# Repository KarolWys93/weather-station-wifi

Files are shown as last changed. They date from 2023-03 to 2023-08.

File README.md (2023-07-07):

# weather-station-wifi
 **Useful links:**
 - [User Manual](Docs/user_manual.md)
 - [Electronics](Hardware/electronics/README.md)
 - [Device case](Hardware/case/README.md)
 - [Local development server](html/README.md)
 - [Web Server API](Docs/http_api_docs.md)
 - [Generation of display images](res/README.md)
 - [Preparation for first start](Docs/preparation.md)

## General description
This is a project of a weather station with WiFi module. The presented forecasts come from the [open-meteo](https://open-meteo.com/) service.

The device is based on the **STM32F103CBT6** microcontroller and the popular WiFi module: **ESP32-C3-WROOM-02**. The WiFi module uses AT command control mode. The project uses a 1.54" 3-color [e-Paper display](https://www.waveshare.com/1.54inch-e-paper-module-b.htm) with a resolution of 200x200 px.

Block diagram of the device:

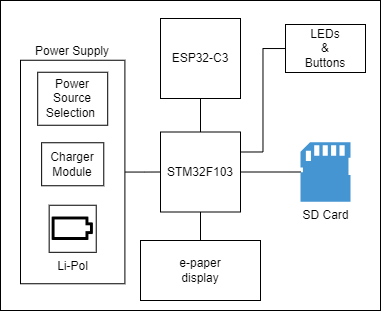
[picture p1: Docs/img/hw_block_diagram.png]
Block diagram of the device


There are two main parts of the firmware: **forecast client** and **http server**.

The task of the forecast client is to decode the postcode to the coordinates (if the coordinates are not provided directly), download the weather forecast for the given coordinates and display it on the e-paper display.

The HTTP server is used in configuration mode. In the configuration mode, the WiFi module starts its own AccessPoint, and the HTTP server provides the configuration website.

## Device visualization:
| Front of the device | 3D view of the device |
|--|--|
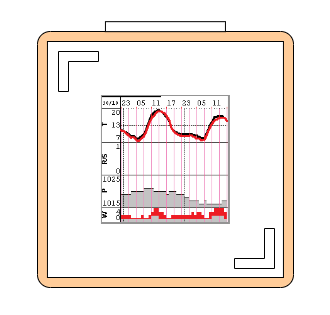
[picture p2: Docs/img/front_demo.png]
front of device
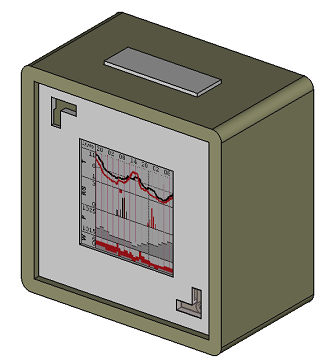
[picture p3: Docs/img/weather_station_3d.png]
3D device image
|  |  |
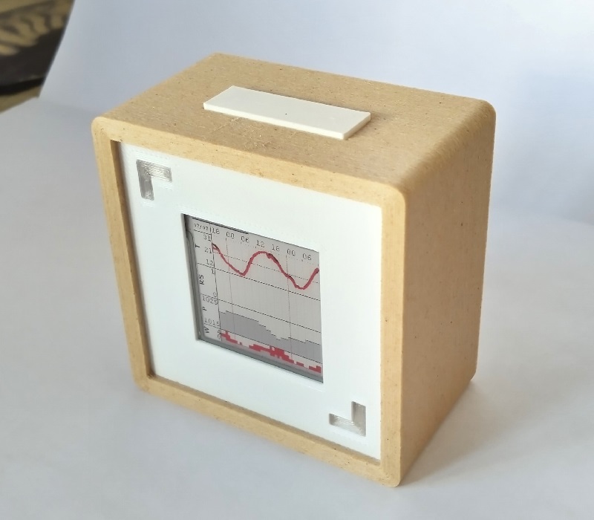
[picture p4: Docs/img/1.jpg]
photo of the device from the front
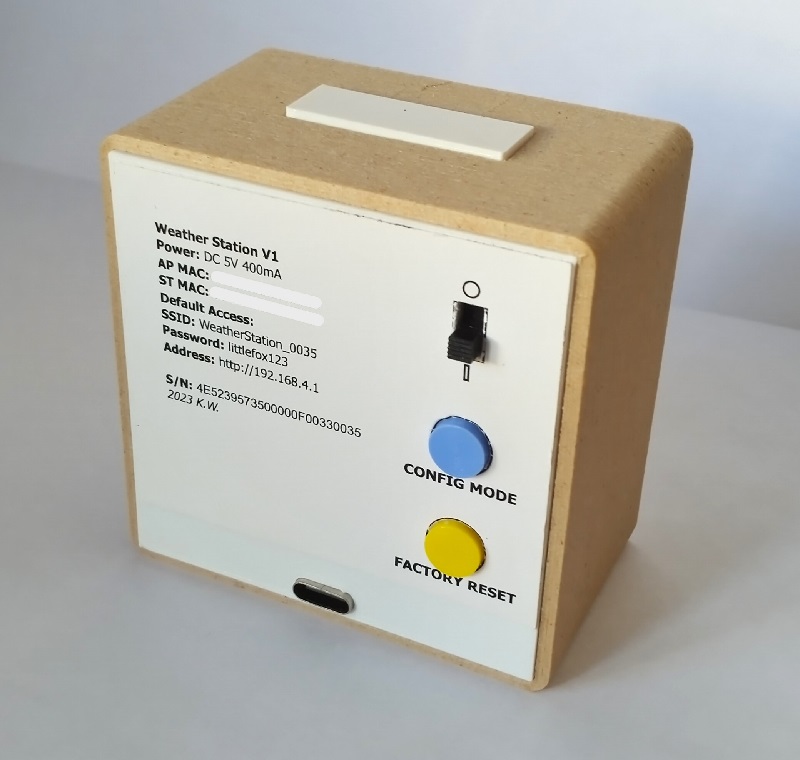
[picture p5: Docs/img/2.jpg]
photo of the device from the back
|  |  |

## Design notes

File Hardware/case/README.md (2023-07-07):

# Device case

The device case has been designed in FreeCad. The project file is stored in `Hardware/case/project` directory.
All case part models in .stl format can be found in `Hardware/case/models` directory.

## Device case scheme

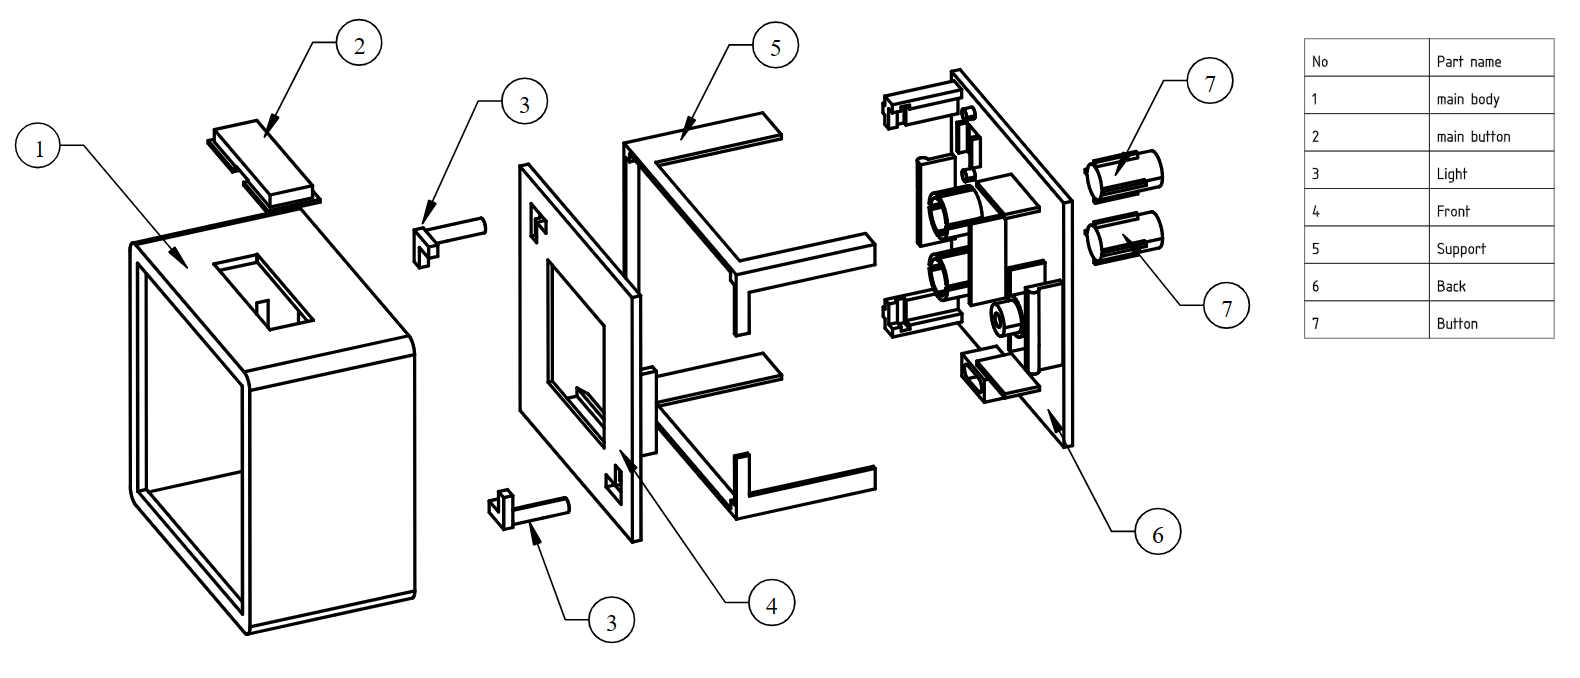
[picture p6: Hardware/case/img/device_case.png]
Device case schema


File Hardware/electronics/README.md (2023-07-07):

# Hardware

The scheme and PCB layout have been designed in KiCad. The project can be found in weather_station.zip archive.

## Jumpers and connectors
| J# | Description |
|--|--|
| J1 | MCU reset |
| J3 | MCU ISP: 1 - SWDIO, 2 - SWCLK, 3 - GND |
| J4 | MCU UART: 1 - RX, 2 - TX, 3 - GND |
| J5 | WiFi module boot mode: on - download mode. off - normal mode |
| J6 | E-Paper display |
| J7 | WiFi module UART: 1 - RXD, 2 - TXD, 3 - GND  |
| J8 | USB power line |
| J9 | Battery |
| J10 | Power switch |
| JP1 | WiFi module enable signal source: 1-2: MCU, 2-3: module always enabled |

## Electrical schematic

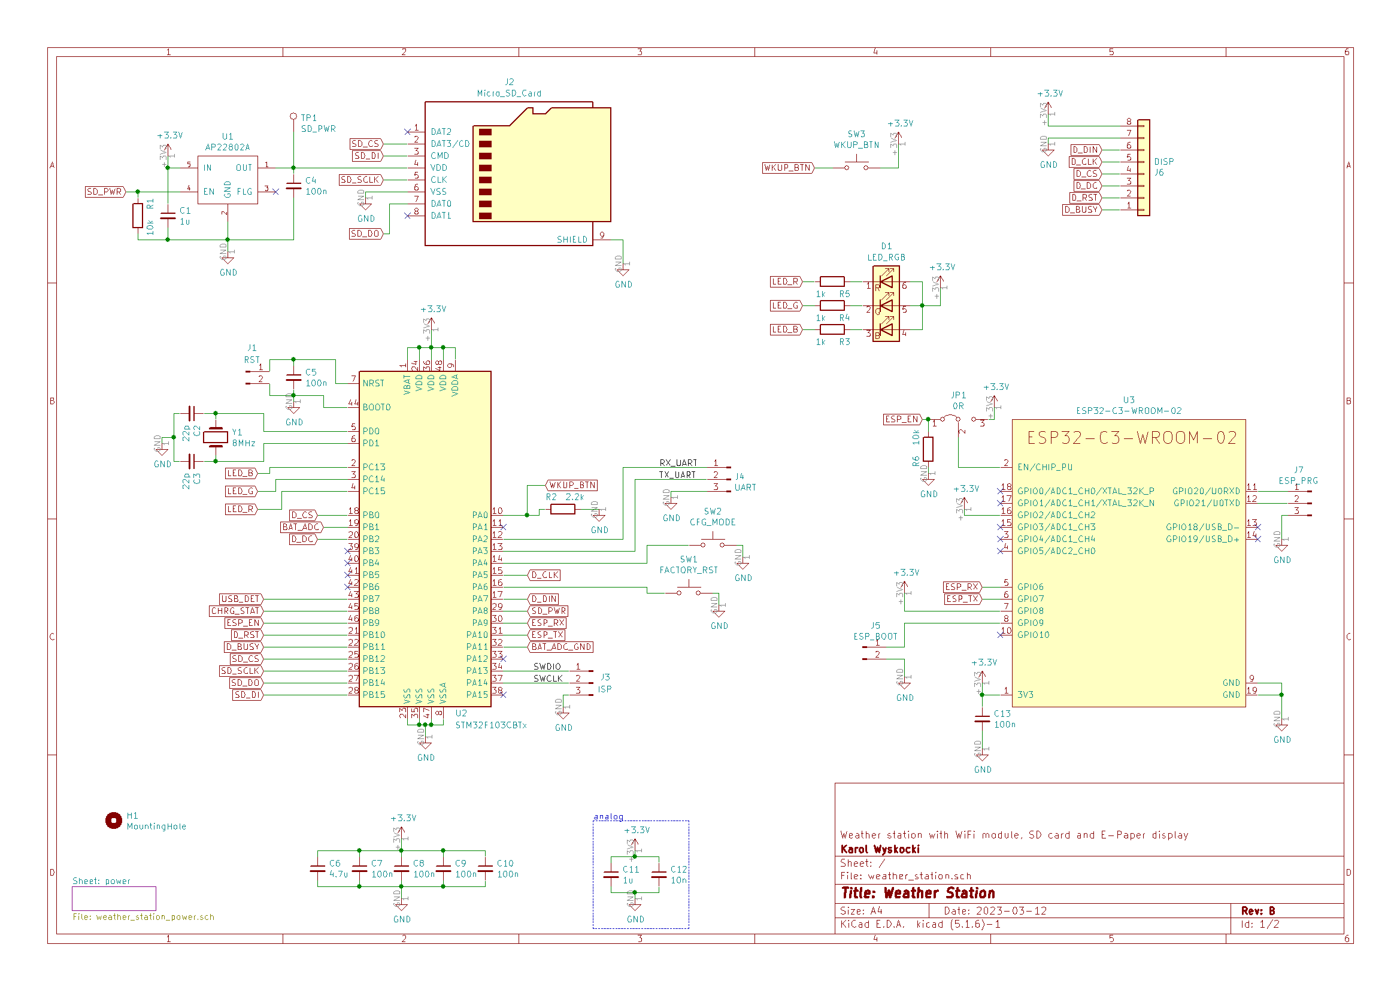
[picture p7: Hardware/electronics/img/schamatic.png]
Main schematic


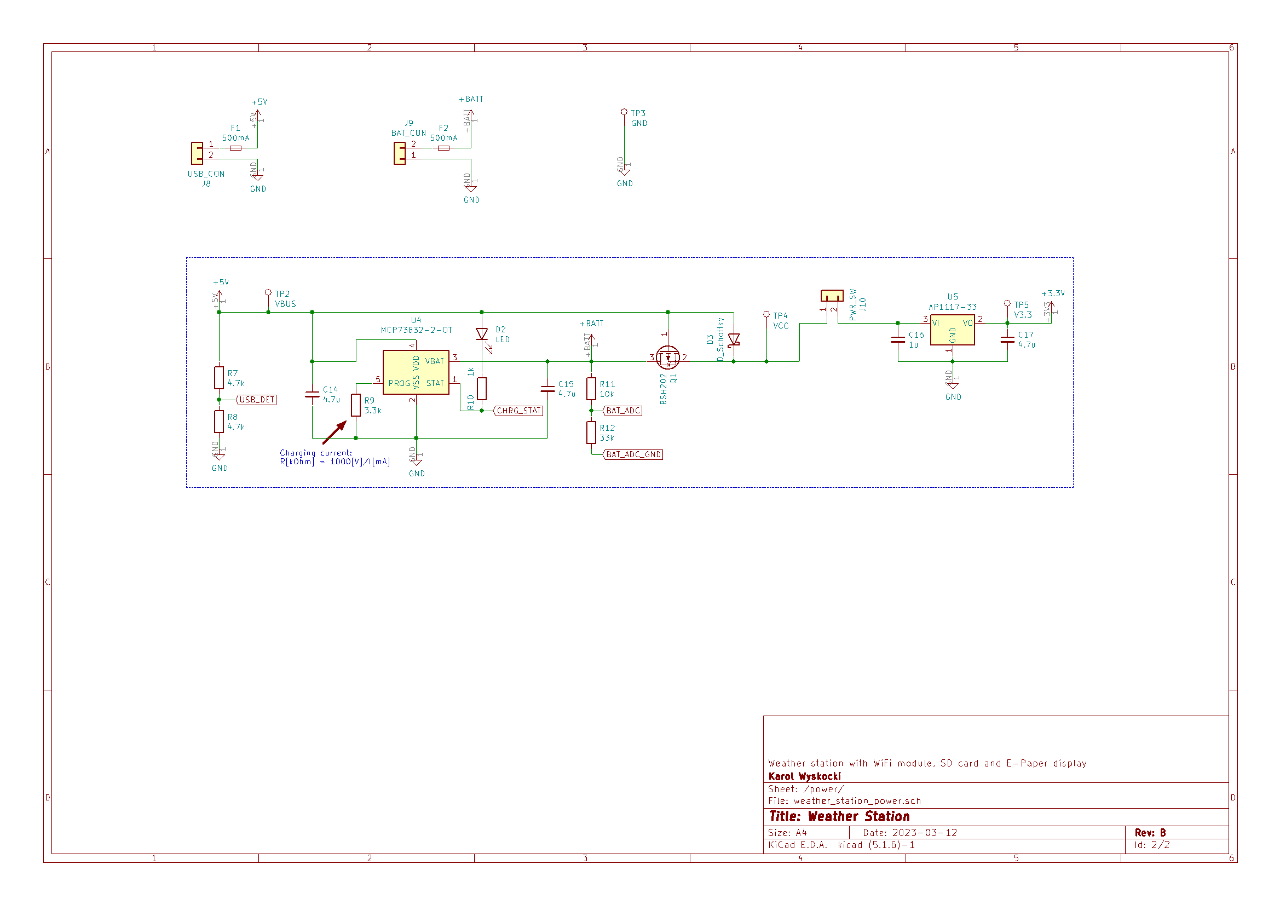
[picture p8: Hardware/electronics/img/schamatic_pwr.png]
Power source block


## PCB view:
| PCB top | PCB bottom |
|--|--|
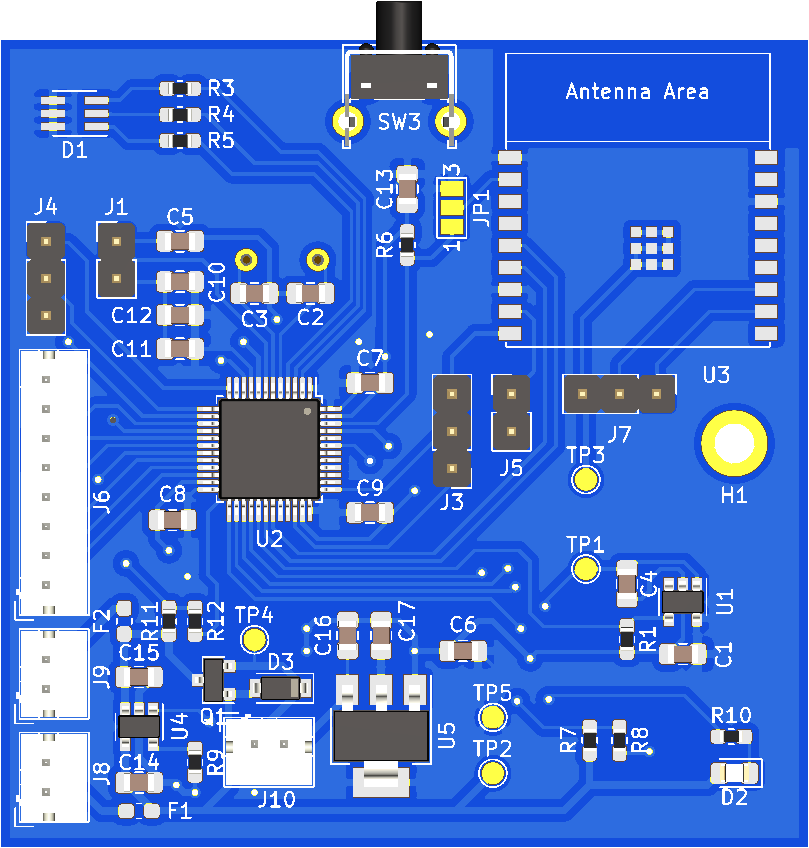
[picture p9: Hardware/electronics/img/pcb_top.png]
top
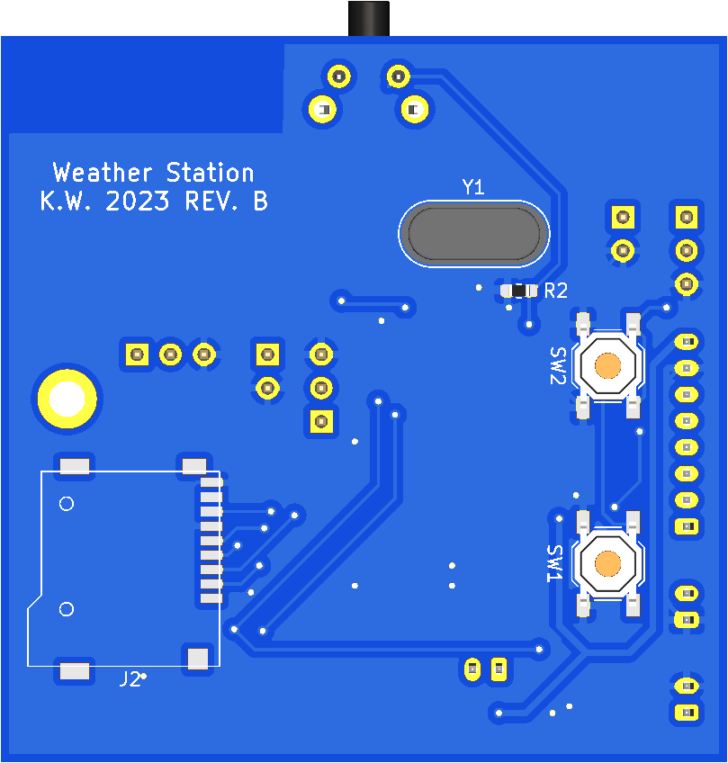
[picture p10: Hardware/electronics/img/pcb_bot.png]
bottom
|  |  |

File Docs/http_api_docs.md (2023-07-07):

# API Docs

## HTTP GET

### GET /api/status
Returns the current state of the device.

Response code: 200

Example of response:

    {
	  "wifi_ssid": "Testowa Sieć",
	  "wifi_stat": 1,
	  "bat": 43,
	  "ip_addr": "192.168.0.129",
	  "charging": 2,
	  "ver": "v1.3.1",
	  "sta_mac": "00:11:22:33:44:55",
	  "ap_mac": "AA:BB:CC:DD:EE:FF",
	  "ver_wifi": "2.1"
    }
Fields in response:

 - **wifi_ssid** - network name
 - **wifi_stat** - connection state: 1 - connected, 0 - disconnected
 - **bat** - battery level in %
 - **ip_addr** - device IP address
 - **charging** - charging status: 0 - no charging, 1 - charging, 2 - power supply on.
 - **ver** - software version
 - **sta_mac** - device MAC address (WiFi client)
 - **ap_mac** - MAC address of the access point (configuration mode)
 - **ver_wifi** - firmware version of the Wi-Fi module

### GET /api/ap_conf
Returns the current network settings of the access point (config mode).

Response code: 200

Example of response:

    {
	  "ap_ssid":"ConfigMode WiFi",
	  "ap_enc":"3",
	  "ap_chl":"8"
    }
Fields in response:
 - **ap_ssid** - network name
 - **ap_enc** - Access Point encryption: 0 - open, 2 - WPA PSK, 3 - WPA2 PSK, 4 - WPA WPA2 PSK
 - **ap_chl** - Wi-Fi channel (1-13)

### GET /api/ap_list
Returns Wi-Fi networks in range.

Response code: 200

Example of response:

    [
      {
        "ssid":"Example WiFi",
        "rssi":-40,
        "enc":4
      },
      {...},...
    ]
Fields in response:
 - **ssid** - network name
 - **enc** - encryption: 0 - open, 2 - WPA PSK, 3 - WPA2 PSK, 4 - WPA WPA2 PSK
 - **rssi** - Wi-Fi signal strength (dBm)

### GET /api/wifi_conf
Returns the current network settings.

Response code: 200

Example of response:

    {
	  "wifi_ssid": "Example WiFi",
	  "dhcp": 1,
	  "wifi_ip": "192.168.0.150",
	  "wifi_mask": "255.255.255.0",
	  "wifi_gw": "192.168.0.1"
    }
Fields in response:
 - **wifi_ssid** - network name
 - **dhcp** - dhcp status: 0 - disable, 1 - enable. Optional if DHCP is disabled.
 - **wifi_ip** - device IP address. Optional if DHCP is enabled.
 - **wifi_mask** - IP mask. Optional if DHCP is enabled.
 - **wifi_gw** - gateway IP address. Optional if DHCP is enabled.

### GET /api/fcast_conf
Returns the current forecast settings.

Response code: 200

Example of response where weather forecast location based on zip code:

    {
	  "api_key":"1234567890asdfghjklpqwertyuiop32",
	  "refresh":2,
	  "country":"PL",
	  "zip_code":"12-345"
    }
and for weather forecast location based on coordinates:

    {
	  "api_key":"1234567890asdfghjklpqwertyuiop32",
	  "refresh":2,
	  "lon": "89.9999999",
	  "lat": "89.9999999"
    }
Fields in responses:
 - **api_key** - geolocation service api key
 - **refresh** - how often the weather forecast is refreshed in hours
 - **country** - country code (ISO 3166-1 alpha-2 code)
 - **zip_code** - zip_code
 - **lon** - longitude
 - **lat** - latitude

### GET /api/system_conf
Returns the current system settings.

Response code: 200

Example of response:

    {
	  "device_name": "Potato1234",
	  "led_ind": 1
    }
Fields in response:
 - **device_name** - name of the device
 - **led_ind** - LED status indicator: 0 - off, 1 - on

### GET /api/restart
Restarts the device in forecast mode.

Response code: 204

### GET /api/restart_conf
Restarts the device in configuration mode.

Response code: 204

### GET /api/restore_config
Restores factory settings.

Response code: 204

## HTTP POST

### POST /api/ap_conf
Set access point configuration (for config mode).

Example request body:

    {
		"ap_ssid": "example_wifi",
		"ap_pass": "secret_password",
		"ap_enc": 4,
		"ap_chl": 8
	}

Request fields:
 - **ap_ssid** - Access Point WiFi name (max 31 chars)
 - **ap_enc** - Access Point encryption: 0 - open, 2 - WPA PSK, 3 - WPA2 PSK, 4 - WPA WPA2 PSK
 - **ap_pass** - Access Point password (min 8, max 62 chars). Not needed if ***ap_enc = 0***
 - **ap_chl** - channel of the access point (1-13)

Response code: 204

### POST /api/wifi_conf
Set WiFi configuration.

Example request body:

    {
		"ssid": "example_wifi",
		"pass": "secret_password",
		"dhcp": 0,
	    "ip": "192.168.0.150",
	    "mask": "255.255.255.0",
	    "gw": "192.168.0.1"
	}

Request fields:
 - **ssid** - WiFi name (max 31 chars)
 - **pass** - Access Point password. If there is no encryption, you can skip it.
 - **dhcp** - dhcp: 0 - disable, 1 - enable. If the field is omitted, DHCP is disabled.
 - **ip** - Device IP address. Required if DHCP is disabled.
 - **mask** - IP mask. Required if DHCP is disabled.
 - **gw** - Gateway IP address. Required if DHCP is disabled.

Response code: 200

Example of response:

    {
	  "code": 0
    }
    
Fields in response:
**code**: 
- 0: connected to the new WiFi station.
- 1: connection timeout.
- 2: wrong password.
- 3: cannot find the target AP.
- 4: connection failed.
- 5: Cannot disable DHCP or set IP addresses.

### POST /api/fcast_conf
Set forecast configuration. Forecast will use geolocation service if zip code and country code are present. Otherwise, the location is based on coordinates.

Example request body:

    {-
      "refresh": 2,
      "country": "PL",
      "zip_code": "12-345",
      "api_key": "1234567890asdfghjklpqwertyuiop32",
      "lon": 8.9999,
      "lat": 8.9999
    }
Request fields:
 - **refresh** - how often the weather forecast will be refreshed in hours. Must be greater than 0.
 - **country** (optional)- country code (ISO 3166-1 alpha-2 code)
 - **zip_code** (optional) - zip_code
 - **api_key** - geolocation service API key. Required if country or zip_code fields are present.
 - **lon** - longitude. Not nedded if country or zip_code fields are present.
 - **lat** - latitude. Not nedded if country or zip_code fields are present.

Response code: 204

### POST /api/device_name
Set device name.

Example request body:

    {
      "device_name": "example_device_name"
    }
Request fields:
 - **device_name** - Device name. The maximum length is 32 characters.

Response code: 204

### POST /api/led_ind
Set device name.

Example request body:

    {
      "led_ind": 1
    }
Request fields:
 - **led_ind** - 0: disable LED indicator, 1: enable LED indicator

Response code: 204

## Debug API

### GET /api/logs?size={size}
Returns device logs.

Call parameters:
 - **size** (optional) - Maximum log size in kB. The maximum value is 512, the default is 20.

Response code: 200

### GET /api/voltage
Returns power supply information.

Response code: 200

Example of response:

    {
      "voltage":"4021",
      "bat_lvl":99,
      "bat_chr":%u
    }

Fields in response:

 - **voltage** - battery voltage in mV
 - **bat_lvl** - battery level in %
 - **bat_chr** - charging status: 0 - no charging, 1 - charging, 2 - power supply on.

### GET /api/led_test
Checks the LED indicator. The LED indicator flashes through all combinations of 8 colors.

Response code: 204

### GET /api/img_test?img={int}&text={text}&sub_text={text}

To check the display, it shows the selected image with text on the device.
Returns device logs.
Call parameters:
 - **text** (optional) - primary text, no longer than 40 bytes. Default empty.
 - **sub_text** (optional) - secondary text, no longer than 50 bytes. Default empty.
 - **img** (optional) - Image number. Default value is 2.

Images:

 0. memory card error image
 1. blank forecast background (text and subtext are not used)
 2. config mode image (text and subtext are not used)
 3. low battery image (text and subtext are not used)
 4. WiFi error image
 5. General error image

Response code: 204 on success or 400 on invalid img number

### GET /api/fcast_tmp
Returns the last forecast file

Response code: 200 on success or 404 if the file does not exist.

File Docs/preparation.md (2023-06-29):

# Preparation for first start

## WiFi module

The device's WiFi module should be programed with AT command firmware. The firmware and all needed tools can be found in links below.

ESP32 AT module firmware:
https://docs.espressif.com/projects/esp-at/en/latest/esp32c3/AT_Binary_Lists/ESP32-C3_AT_binaries.html

ESP32 tools and downloading guide:
https://docs.espressif.com/projects/esp-at/en/latest/esp32c3/Get_Started/Downloading_guide.html

### Jumpers and connectors:
- JP1 - select ESP_Enable signal source: 1-2: MCU, 2-3: module always enabled
- J5 - Jumper on: download mode. Jumper off: normal mode
- J7 - ESP32 uart connector: 1 - RXD, 2 - TXD, 3 - GND 

Before flashing, the JP1 solder bridge should connect pins 2 and 3 to make sure the module is powered on when firmware downloading.
Jumper J5 must be connected before powering on to enter download mode.

## MCU

- J1 - Connect to reset STM32F1 MCU.
- J3 - MCU programming connector: 1 - SWDIO, 2 - SWCLK, 3 - GND

## SD Card preparation
The device uses an SD memory card to store static HTML files, graphics, configurations and logs. The first partition on the memory card should be formatted as FAT32 with a block size of 512B. Partition size can be up to 2GB.

Fresh formated memory card should contains directories:
- `img` - contains images (see [Generation of display images](../res/README.md))
- `html` - contains static html files (see [Local development server](../html/README.md))

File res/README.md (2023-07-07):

# Images

The E-Paper display used in the device has a resolution of 200x200 pixels and supports up to 5 colors: black, white, red, gray and pink. The display driver uses 3 "images" for black, gray and pink. A red color pixel is obtained when the same pixel is set for a black and pink "image".

## Image list

Here is the list of images used in system. Every image has its own index:

- 0 - memory error image *
- 1 - forecast background image *
- 2 - configuration mode image
- 3 - Low battery image
- 4 - wifi error image
- 5 - general error image

Memory error and forecast background images are loaded from the FLASH memory. The rest of the images are stored on the SD memory card. Images on the SD card are stored in **/img/** directory as epd files. The file name format is:
***/img/x_y.epd***
Where *x* is index and *y* is color. Example:
*/img/2_b.epd  
/img/2_g.epd  
/img/2_r.epd*

The example shows configuration mode images for black, grey and red display colors. It isn't mandatory to provide epd file if it is blank.

## Creating and converting images

Images should have a resolution of 200x200 pixels and use only the colors listed:
0x000000 : black  
0xED1C24 : red  
0xC3C3C3 : grey  
0xEF88BE : pink  
0xFFFFFF : white

Prepared image have to be split into monochrome bitmaps using script ***color_split.py***. Example:

`python res/scripts/color_split.py res/low_bat.bmp`

The result is 3 monochrome bitmaps:
*low_bat_b.bmp  
low_bat_g.bmp  
low_bat_r.bmp*

### Converting to file
Now these bitmaps should be converted to edp files. edp file is a raw image buffer for displaying e-paper.
The conversion can be done using the script ***epd_conv.py***. Example:

`python res/scripts/epd_conv.py res/low_bat_b.bmp`

The result is *low_bat_b.epd* file.
Now the file can be moved to the SD card (and renamed respectively).

### Converting to code
If image should be stored in FLASH memory, then image file can be converted to code (text). Example:

`python res/scripts/epd_conv.py -t res/low_bat_b.bmp`

The output is a text file. The content of the file should be copy to source code as array.

## "Screenshots" and back conversion

For debugging purposes, display buffers can be dumped to files. The dumps are saved as epd files in ***/img/scr*** directory.
The epd files can be converted to image using script ***scr2img.py***. Example:

`python res/scripts/scr2img.py b.epd g.epd r.epd output_img.bmp`

## Dependences

All the mentioned python scripts require the numpy and PIL libraries.

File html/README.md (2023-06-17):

# HTML static files

The html directory contains all the necessary static files for the device's web server. The api_mock directory contains mock APIs for testing the server on a local machine. These mocks are examples of server responses to various requests.
The device stores all website static files in the *'html"* directory on the SD card.

## Static files compression 
The http server always returns static files compressed with gzip (Content-Encoding set as gzip). The web server does not have a compression function implemented, so static files must be compressed beforehand.
To prepare the files for the server, run the ***compress.sh*** script.
The script creates a new directory *"compressed"*, copies the *"html"* directory there and compresses all files to the desired format. The *"html"* directory from the *"compressed"* directory can be copied to the root directory of the SD card.

## Test server
The test server can be used to test a website locally without the weather station device.
To enable test server, run the ***server_test.bat*** script. The script copies the static and mock files to the "test_server" directory and then starts a simple Python HTTP server. The server is listening for a connection on port **8000**.
The server works on a copy of the files, so any changes will be visible after restarting the server.

## Server web API
The web server API documentation can be found [here](../Docs/http_api_docs.md).

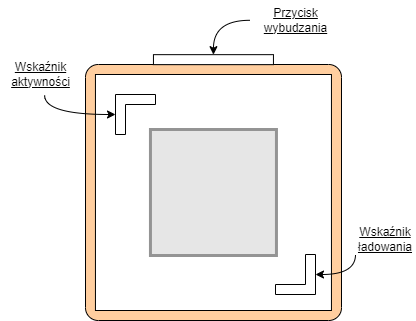
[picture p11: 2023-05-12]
html/html/pl/img/front.png

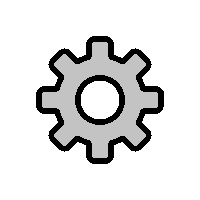
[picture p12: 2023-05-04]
res/settings.bmp

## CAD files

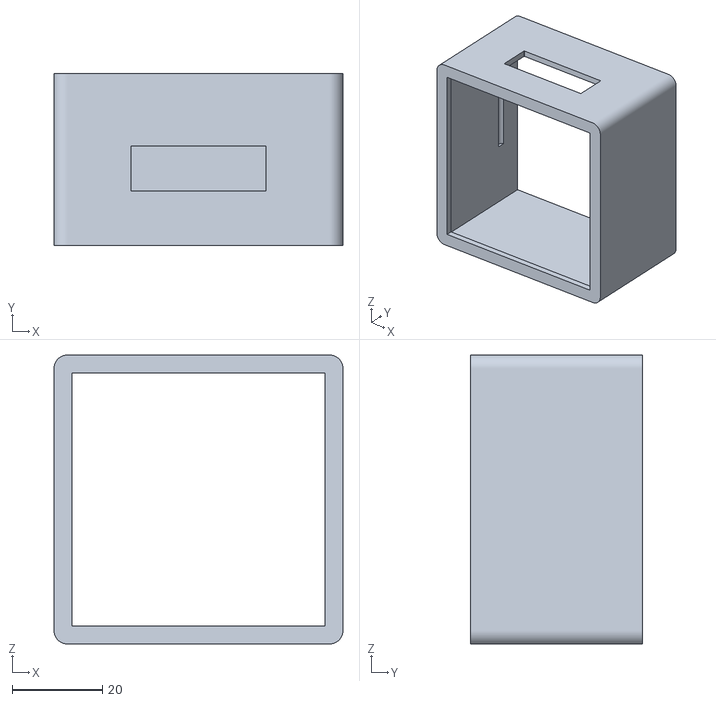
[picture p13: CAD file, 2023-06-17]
Hardware/case/models/main_body.stl
64.0 x 38.0 x 64.0

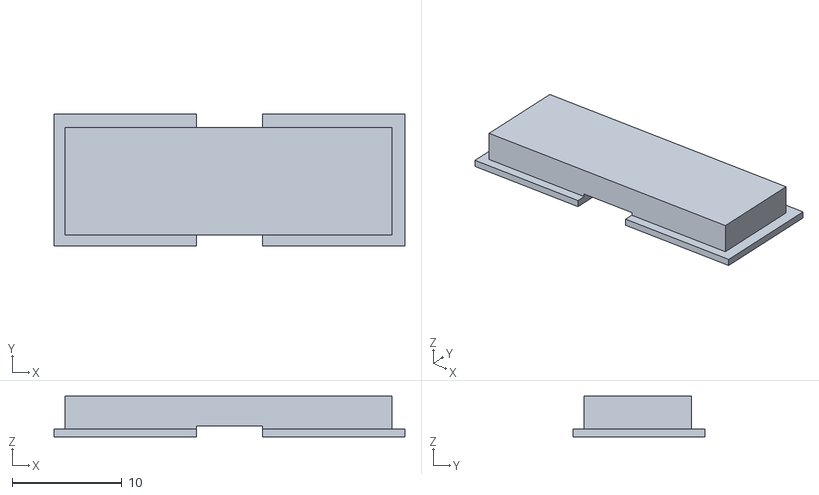
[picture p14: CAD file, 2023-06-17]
Hardware/case/models/button_main.stl
32.0 x 12.0 x 3.70

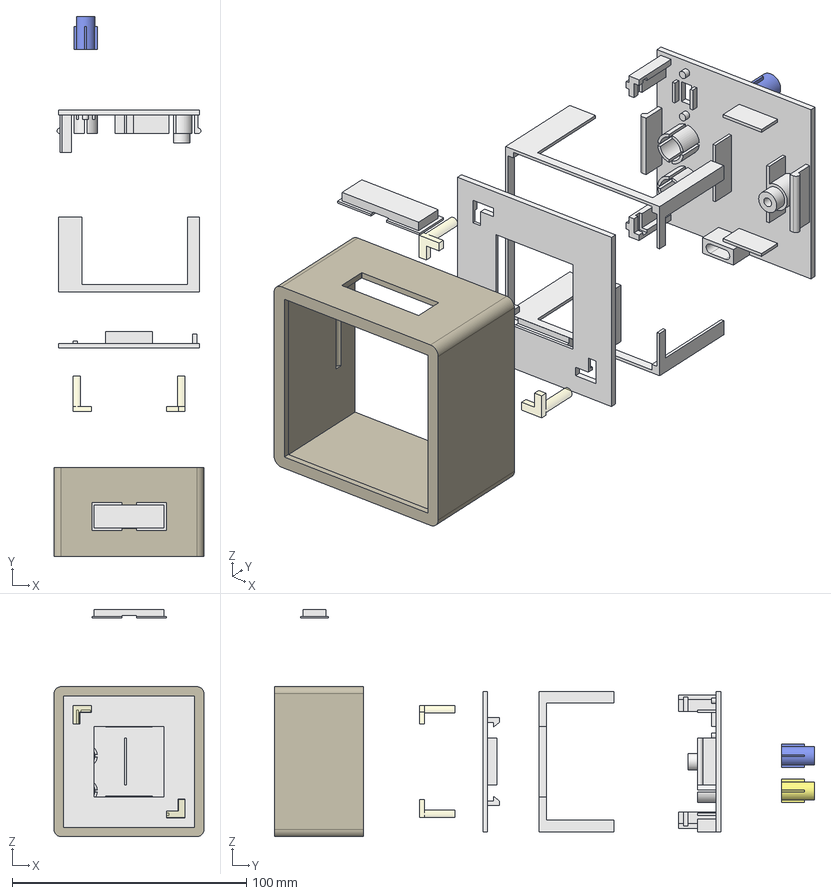
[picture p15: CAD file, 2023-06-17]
Hardware/case/project/weather_station.FCStd
64.0 x 230.5 x 97.0 mm
front
main_body
light
light_clone
back
button
button_main
button_clone
support

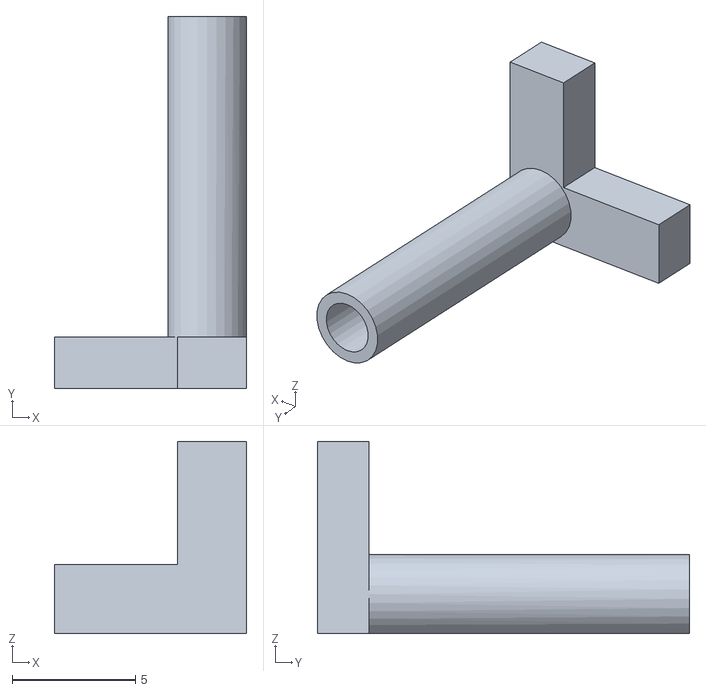
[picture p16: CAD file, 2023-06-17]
Hardware/case/models/light.stl
7.80 x 15.1 x 7.80

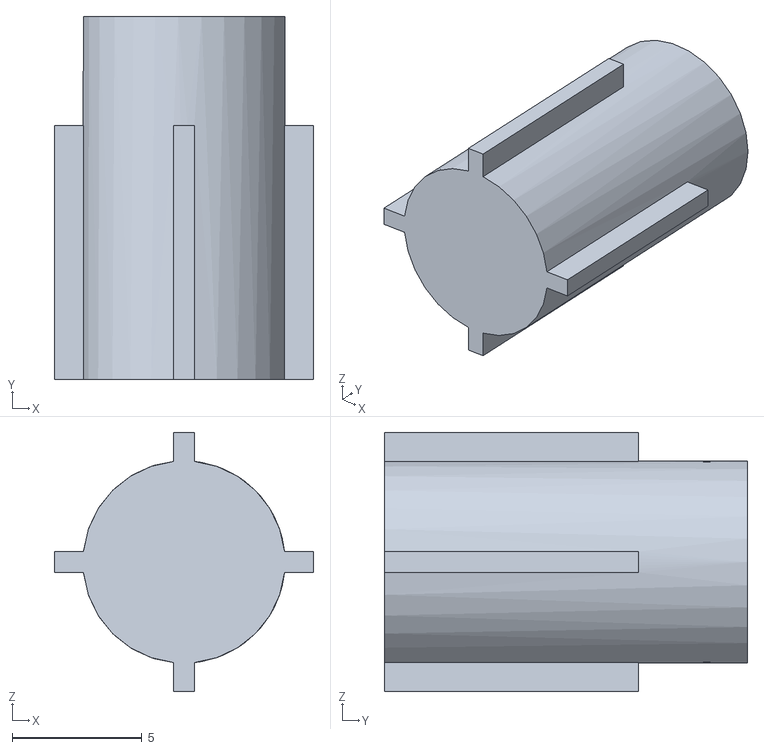
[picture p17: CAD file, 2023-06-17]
Hardware/case/models/button.stl
10.0 x 14.0 x 10.0

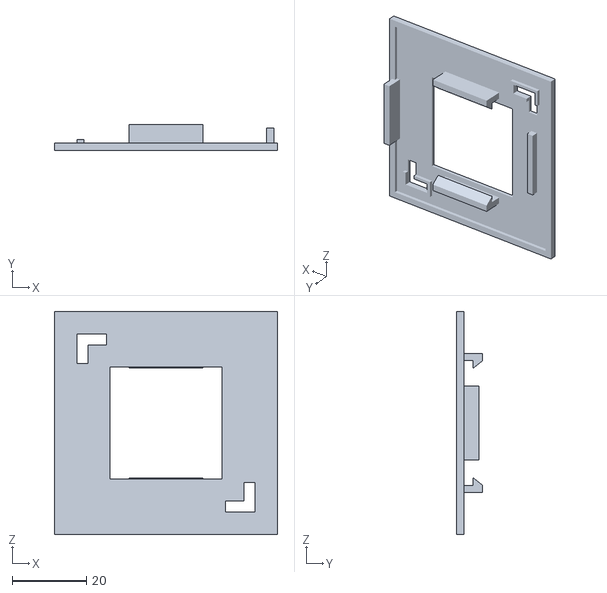
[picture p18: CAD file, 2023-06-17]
Hardware/case/models/front.stl
60.0 x 7.00 x 60.0

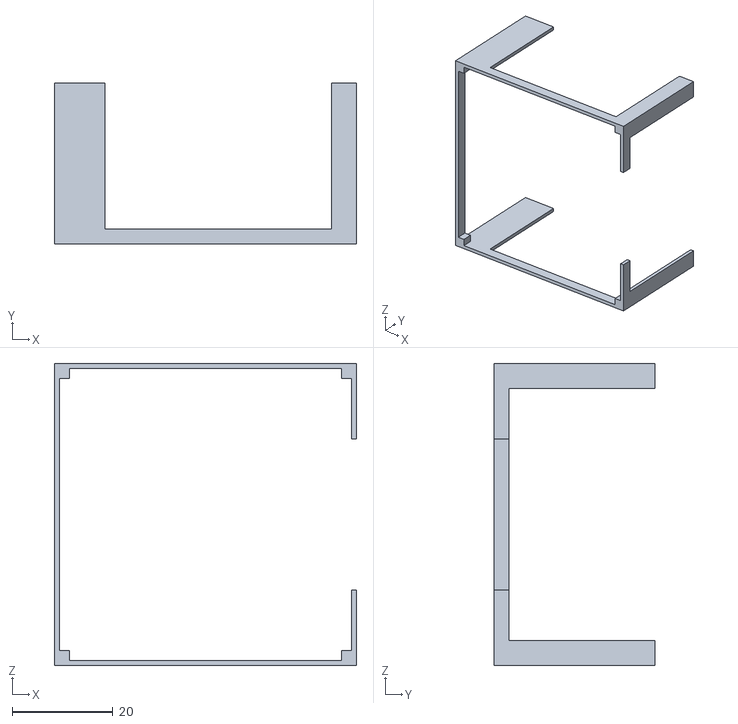
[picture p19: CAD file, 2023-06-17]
Hardware/case/models/support.stl
60.0 x 32.0 x 60.0

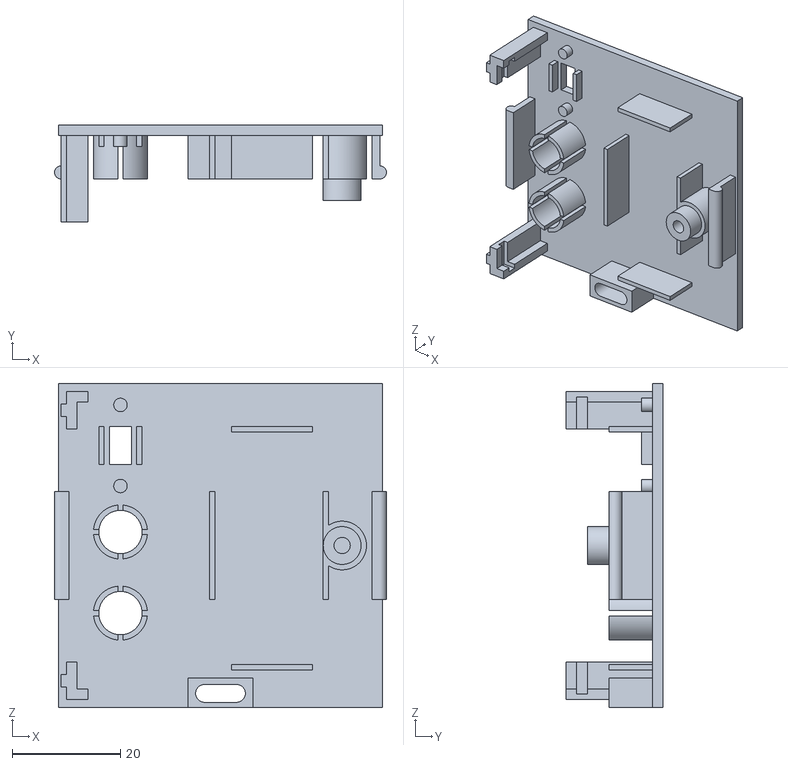
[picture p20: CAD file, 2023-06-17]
Hardware/case/models/back.stl
61.4 x 18.0 x 60.0

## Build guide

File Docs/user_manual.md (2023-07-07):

# User manual

## Front of the device

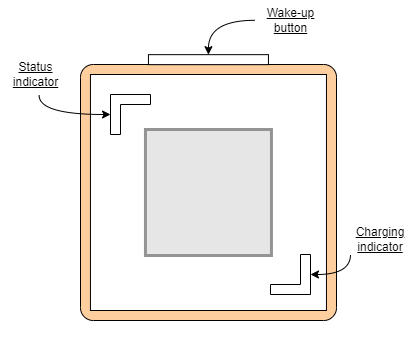
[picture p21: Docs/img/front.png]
front view of device


*   **Charging indicator:** Lights up when charging is in progress.
*   **Status indicator:**
    *   green - device is active
    *   blue - device in config mode
    *   red - error occurred
    *   yellow - indicates restart after hang-up condition
    *   cyan - factory reset
    *   white - critical error occurred. Manual restart needed
    *   **Wake-up button:** Wakes the device from sleep mode.

## Forecast display

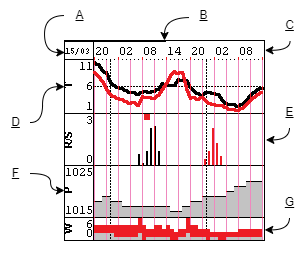
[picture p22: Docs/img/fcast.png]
example forecast display


Legend:

*   **A -** Forecast date.
*   **B -** Battery level.
*   **C -** Time line. The pink vertical line separates the 3 hour segments. The dashed line separates the days.
*   **D -** Temperature in °C. The black line is the real temperature, the red line is the apparent temperature.
*   **E -** Rain (black) in mm and snowfall (red) in cm. The red square means a storm.
*   **F -** Atmospheric pressure in hPa.
*   **G -** Wind speed (grey) and gusts (red) in Beaufort scale.

| Beaufort number | Description | Wind speed |
|--|--|--|
| 0 | Calm | < 2 km/h, < 0.5 m/s |
| 1 | Light air | 2-5 km/h, 0.5-1.5 m/s |
| 2 | Light breeze | 6-11 km/h, 1.6-3.3 m/s |
| 3 | Gentle breeze | 12-19 km/h, 3.4-5.5 m/s |
| 4 | Moderate breeze | 20-28 km/h, 5.6-7.9 m/s |
| 5 | Fresh breeze | 29-38 km/h, 8.0-10.7 m/s |
| 6 | Strong breeze | 39-49 km/h, 10.8-13.8 m/s  |
| 7 | High wind | 50-61 km/h, 13.9-17.1 m/s |
| 8 | Gale | 62-74 km/h, 17.2-20.7 m/s |
| 9 | Strong gale | 75-88 km/h, 20.8-24.4 m/s |
| 10 | Storm | 89-102 km/h, 24.5-28.4 m/s |
| 11  | Violent storm | 103-117 km/h, 28.5-32.6 m/s |
| 12 | Hurricane-force | ≥ 118 km/h, ≥ 32.7 m/s |

## Config mode

To enter the configuration mode, hold the blue button on the back of the device and at the same time wake up the device by pressing the wake-up button (on the top of the case) or turning on the power (power switch).

In config mode, the device enables its own WiFi Access Point. The default WiFi name is **WeatherStation\_xxxx** (where xxxx is the end of the serial number) and the password is **littlefox123**. The default WiFi name and password can be changed in the Access Point tab.

The configuration website is available at http://192.168.4.1. To exit the configuration mode, hold down the wake button or select the appropriate option in the System tab.

## Factory reset

The device can be restored to the default settings in System tab. A factory reset can also be performed by holding down the yellow button on the back of the device while switching power on. After the factory reset, the device will reboot into configuration mode.

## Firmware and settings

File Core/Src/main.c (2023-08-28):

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
/* Includes ------------------------------------------------------------------*/
#include "main.h"
#include "adc.h"
#include "dma.h"
#include "fatfs.h"
#include "rtc.h"
#include "spi.h"
#include "tim.h"
#include "usart.h"
#include "gpio.h"

/* USER CODE BEGIN Includes */
#include <stdlib.h>
#include <stdio.h>
#include <string.h>
#include "wifi/wifi_esp.h"
#include "system.h"
#include "jsmn.h"
#include "app/server/httpServerApp.h"
#include "app/client/forecast_client.h"
#include "logger.h"
#include "utils.h"

#include "led.h"
#include "images.h"
#include "sw_watchdog.h"
#include "GUI/GUI_Paint.h"
#include "e-Paper/EPD_1in54b.h"
/* USER CODE END Includes */


/* USER CODE BEGIN PV */
char deviceName[32] = "";
/* USER CODE END PV */

void SystemClock_Config(void);
/* USER CODE BEGIN 0 */

Wifi_RespStatus loadWiFiAPConfig(void)
{
	SWiFi_AP_Config ap_config;
	FIL configFile;

	char apConfigStr[256];
	uint16_t apConfigSize = 0;

	jsmn_parser jsonParser;
	jsmntok_t jsonTokens[10];
	int16_t numOfTokens;

	uint16_t tokenSize;
	char* tokenPtr;

	DMA_memset(&ap_config, 0, sizeof(SWiFi_AP_Config));

	jsmn_init(&jsonParser);

	if(FR_OK == f_open(&configFile, FILE_PATH_AP_CONFIG, FA_READ))
	{
		if(FR_OK != f_read(&configFile, apConfigStr, sizeof(apConfigStr), (UINT*)&apConfigSize))
		{
			f_close(&configFile);
			Logger(LOG_ERR, "Cannot read AP config");
			return WIFI_RESP_ERROR;
		}
		f_close(&configFile);
	}
	else
	{
		Logger(LOG_ERR, "Cannot open AP config");
		return WIFI_RESP_ERROR;
	}

	numOfTokens = jsmn_parse(&jsonParser, apConfigStr, apConfigSize, jsonTokens, sizeof(jsonTokens) / sizeof(jsonTokens[0]));
	if(0 > numOfTokens || jsonTokens[0].type != JSMN_OBJECT)	//if no tokens or first token isn't object
	{
		Logger(LOG_ERR, "AP config corrupted");
		return WIFI_RESP_ERROR;
	}

	for(uint16_t i = 1; i < numOfTokens; i++)
	{
		if(0 == jsmn_eq(apConfigStr, &jsonTokens[i], "ssid"))
		{
			tokenSize = jsonTokens[i + 1].end - jsonTokens[i + 1].start;
			tokenPtr = apConfigStr + jsonTokens[i + 1].start;
			DMA_memcpy(ap_config.ssid, tokenPtr, tokenSize);
			i++;
		}
		else if(0 == jsmn_eq(apConfigStr, &jsonTokens[i], "pass"))
		{
			tokenSize = jsonTokens[i + 1].end - jsonTokens[i + 1].start;
			tokenPtr = apConfigStr + jsonTokens[i + 1].start;
			DMA_memcpy(ap_config.pass, tokenPtr, tokenSize);
			i++;
		}
		else if(0 == jsmn_eq(apConfigStr, &jsonTokens[i], "enc"))
		{
			WiFi_Encryption encVal = (WiFi_Encryption)atoi(apConfigStr + jsonTokens[i + 1].start);
			ap_config.enc = encVal;
			i++;
		}
		else if(0 == jsmn_eq(apConfigStr, &jsonTokens[i], "channel"))
		{
			uint8_t channelVal = atoi(apConfigStr + jsonTokens[i + 1].start);
			ap_config.channel = channelVal;
			i++;
		}
		else
		{
			i++;
		}
	}

	ap_config.maxConnection = 1;

	return WiFi_AP_mode(&ap_config);
}

/* USER CODE END 0 */

/**
  * @brief  The application entry point.
  * @retval int
  */
int main(void)
{
  /* MCU Configuration--------------------------------------------------------*/

  /* Reset of all peripherals, Initializes the Flash interface and the Systick. */
  HAL_Init();

  /* Configure the system clock */
  SystemClock_Config();

  /* Initialize all configured peripherals */
  MX_GPIO_Init();
  MX_DMA_Init();
  MX_ADC1_Init();
  MX_RTC_Init();
  MX_SPI2_Init();
  MX_USART1_UART_Init();
  MX_USART2_UART_Init();
  MX_FATFS_Init();
  MX_SPI1_Init();
  MX_TIM4_Init();
  MX_TIM3_Init();
  /* Infinite loop */
  /* USER CODE BEGIN WHILE */
  uint16_t retryCounter = 0;

  //Set display canvas setting
  Paint_NewImage(NULL, EPD_WIDTH, EPD_HEIGHT, ROTATE_270, WHITE);

  led_setColor(LED_GREEN);
  system_init();

  if(system_batteryLevel() == 0 && SYSTEM_POWER_BATTERY == system_powerStatus())
  {
	  show_low_bat_image();
	  system_shutdown();
  }

  //WiFi restart procedure
  while (1)
  {
	  if(WIFI_RESP_OK == WiFi_restart(5000))
	  {
		  char WiFi_verString[10];

		  Logger(LOG_INF, "WiFi restart OK!");
		  WiFi_setStationName(system_getHostName(), 1000);
		  if(WIFI_RESP_OK == WiFi_GetVersionString(WiFi_verString, 20, 1000))
		  {
			  Logger(LOG_VIP, "WiFi version: %s", WiFi_verString);
		  }
		  break;
	  }
	  else
	  {
	      sw_watchdog_reset();
		  retryCounter++;
		  Logger(LOG_ERR, "WiFi restart failed %d times", retryCounter);
		  if(retryCounter > 5)
		  {
			  WiFi_shutdown();
			  show_error_image(ERR_IMG_GENERAL, "WIFI Module Error", NULL);
			  for(uint8_t i = 0; i < 20; i++)
			  {
				  led_setColor(LED_RED);
				  system_sleep(250);
				  led_setColor(LED_OFF);
				  system_sleep(250);
			  }
			  system_shutdown();
		  }
		  WiFi_shutdown();
		  system_sleep(1000);
	  }
  }

  //If WIFI config file doesn't exist, stop connecting with old AP
  if(FR_NO_FILE == f_stat(FILE_PATH_WIFI_CONFIG, NULL))
  {
	  WiFi_DisconnectStation(1000);
	  WiFi_setStationAutoConnection(0, 1000);
  }

  Logger(LOG_INF, "Set SNTP config");
  WiFi_setSNTPconfig(1, 0, 1000);
  system_sleep(1000);

  //start applications
  if(system_isConfigModeOn())
  {
	  sw_watchdog_reset();
	  f_unlink(FILE_PATH_CONFIG_MODE_FLAG);

	  if(WIFI_RESP_OK == loadWiFiAPConfig())
	  {
		  Logger(LOG_VIP, "Enter config mode");
		  show_configMode_image();

		  int8_t serverExitCode = 0;
		  Logger(LOG_INF, "Start server");
		  if(0 != (serverExitCode = runServerApp(80, 5, 1000)))
		  {
			  Logger(LOG_ERR, "Server exit with code %d", serverExitCode);
			  char errStr[20];
			  sprintf(errStr, "ecode: %d", serverExitCode);
			  show_error_image(ERR_IMG_GENERAL, "Fatal Server Err", errStr);
		  }
	  }
	  else
	  {
		  show_error_image(ERR_IMG_GENERAL, "WIFI AP Error", "Cannot start AP");
	  }
  }
  else
  {
	  runForecastApp();
  }

  sw_watchdog_reset();
  system_shutdown();	//set system in standby mode

  while (1)
  {
    /* USER CODE END WHILE */

    /* USER CODE BEGIN 3 */
  }
  /* USER CODE END 3 */
}

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


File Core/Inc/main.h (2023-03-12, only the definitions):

#define LED_G_Pin GPIO_PIN_13
#define LED_G_GPIO_Port GPIOC
#define LED_R_Pin GPIO_PIN_14
#define LED_R_GPIO_Port GPIOC
#define LED_B_Pin GPIO_PIN_15
#define LED_B_GPIO_Port GPIOC
#define SYS_WKUP_Pin GPIO_PIN_0
#define SYS_WKUP_GPIO_Port GPIOA
#define CONFIG_MODE_Pin GPIO_PIN_4
#define CONFIG_MODE_GPIO_Port GPIOA
#define D_CLK_Pin GPIO_PIN_5
#define D_CLK_GPIO_Port GPIOA
#define FACTORY_RST_Pin GPIO_PIN_6
#define FACTORY_RST_GPIO_Port GPIOA
#define D_DIN_Pin GPIO_PIN_7
#define D_DIN_GPIO_Port GPIOA
#define D_CS_Pin GPIO_PIN_0
#define D_CS_GPIO_Port GPIOB
#define BAT_ADC_Pin GPIO_PIN_1
#define BAT_ADC_GPIO_Port GPIOB
#define D_DC_Pin GPIO_PIN_2
#define D_DC_GPIO_Port GPIOB
#define D_RST_Pin GPIO_PIN_10
#define D_RST_GPIO_Port GPIOB
#define D_BUSY_Pin GPIO_PIN_11
#define D_BUSY_GPIO_Port GPIOB
#define SD_CS_Pin GPIO_PIN_12
#define SD_CS_GPIO_Port GPIOB
#define SD_CLK_Pin GPIO_PIN_13
#define SD_CLK_GPIO_Port GPIOB
#define SD_MISO_Pin GPIO_PIN_14
#define SD_MISO_GPIO_Port GPIOB
#define SD_MOSI_Pin GPIO_PIN_15
#define SD_MOSI_GPIO_Port GPIOB
#define SD_PWR_Pin GPIO_PIN_8
#define SD_PWR_GPIO_Port GPIOA
#define ESP_TX_Pin GPIO_PIN_9
#define ESP_TX_GPIO_Port GPIOA
#define ESP_RX_Pin GPIO_PIN_10
#define ESP_RX_GPIO_Port GPIOA
#define BAT_ADC_GND_Pin GPIO_PIN_11
#define BAT_ADC_GND_GPIO_Port GPIOA
#define SWDIO_Pin GPIO_PIN_13
#define SWDIO_GPIO_Port GPIOA
#define SWCLK_Pin GPIO_PIN_14
#define SWCLK_GPIO_Port GPIOA
#define USB_DET_Pin GPIO_PIN_7
#define USB_DET_GPIO_Port GPIOB
#define BAT_CHR_Pin GPIO_PIN_8
#define BAT_CHR_GPIO_Port GPIOB
#define ESP_EN_Pin GPIO_PIN_9
#define ESP_EN_GPIO_Port GPIOB

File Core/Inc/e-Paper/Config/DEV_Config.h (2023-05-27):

/*****************************************************************************
* | File      	:   DEV_Config.h
* | Author      :   Waveshare team
* | Function    :   Hardware underlying interface
* | Info        :
*                Used to shield the underlying layers of each master 
*                and enhance portability
*----------------
* |	This version:   V2.0
* | Date        :   2018-10-30
* | Info        :
* 1.add:
*   UBYTE\UWORD\UDOUBLE
* 2.Change:
*   EPD_RST -> EPD_RST_PIN
*   EPD_DC -> EPD_DC_PIN
*   EPD_CS -> EPD_CS_PIN
*   EPD_BUSY -> EPD_BUSY_PIN
* 3.Remote:
*   EPD_RST_1\EPD_RST_0
*   EPD_DC_1\EPD_DC_0
*   EPD_CS_1\EPD_CS_0
*   EPD_BUSY_1\EPD_BUSY_0
* 3.add:
*   #define DEV_Digital_Write(_pin, _value) bcm2835_gpio_write(_pin, _value)
*   #define DEV_Digital_Read(_pin) bcm2835_gpio_lev(_pin)
*   #define DEV_SPI_WriteByte(__value) bcm2835_spi_transfer(__value)
#
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
******************************************************************************/
#ifndef _DEV_CONFIG_H_
#define _DEV_CONFIG_H_

#include "main.h"
#include "stm32f1xx_hal.h"
#include "stm32f1xx_hal_gpio.h"
#include <stdint.h>

/**
 * data
**/
#define UBYTE   uint8_t
#define UWORD   uint16_t
#define UDOUBLE uint32_t

/**
 * e-Paper GPIO
**/
#define EPD_RST_PIN     D_RST_GPIO_Port, D_RST_Pin
#define EPD_DC_PIN      D_DC_GPIO_Port, D_DC_Pin
#define EPD_CS_PIN      D_CS_GPIO_Port, D_CS_Pin
#define EPD_BUSY_PIN    D_BUSY_GPIO_Port, D_BUSY_Pin

/**
 * GPIO read and write
**/
#define DEV_Digital_Write(_pin, _value) HAL_GPIO_WritePin(_pin, _value == 0? GPIO_PIN_RESET:GPIO_PIN_SET)
#define DEV_Digital_Read(_pin) HAL_GPIO_ReadPin(_pin)

/**
 * delay x ms
**/
#define DEV_Delay_ms(__xms) system_sleep(__xms)

void DEV_SPI_WriteByte(UBYTE value);
void DEV_SPI_AsyncWriteBytes(UBYTE *value, UWORD size);
void DEV_SPI_WaitForEndAsyncWrite(void);
#endif

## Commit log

2022-10-03 Add project files
    [sdcard_esp Debug.cfg, sdcard_esp Release.cfg]
2022-10-03 Add "low battery" warning and ADC values filtering
2022-10-03 Change power supply info on status page
2022-10-12 Fix getting uC unique serial number
    [system.c]
2022-10-13 Fix restart source detection
    [rtc.c, system.c]
2022-10-17 Migrate to new IDE and cube MX version
    [sdcard_esp Debug.cfg, sdcard_esp Release.cfg]
2022-10-20 Add factory reset button
2022-10-22 Add multi-color led indicators
2022-10-23 Move button handling to separate file
2022-11-21 Add SD Card power pin for power key
2022-12-14 Fix temperature rounding error for negative values
2023-03-20 Adaptation to new hardware
    [weather_wifi_3CBT6.cfg]
2023-03-23 Detect charging and DC adapter as separate events
2023-03-24 Logging to UART
2023-03-24 Fix unknow reste cause bug
    [system.c]
2023-03-26 Add battery level on error images
    [system.c, system_power.c]
2023-03-30 Add LSI calibration
2023-04-02 Fix emergency factory reset bug
    Despite factory reset due to inconsistent data,
    the device was still connecting to the access point.
    Now after factory reset the device doesn't connect
    to the old AP.
    [main.c]
2023-04-02 Add a progressive retry time.
    Each retry time is longer. This should prevent battery
    from draining when cannot connect to Wi-Fi or the server
    is down.
    [backup_registers.c, rtc.c, sw_watchdog.c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]
2023-04-07 Move SD Card power off/on to sd driver
2023-04-08 Add interrupt handling in the SD card driver.
2023-04-08 Add led_test API
2023-04-21 Increase RTC time correction
    [rtc.c]
2023-04-23 Implement UART ring buffer
2023-05-05 Fix "received -1 bytes" problem.
    [usart.c, wifi_esp.c]
2023-05-05 Fix dma memcpy stall state.
    [dma.c]
2023-05-27 Add sending img buffers via DMA
2023-06-17 Add device case project
    [back.stl, button.stl, button_main.stl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]
2023-07-07 Add a photo of the device
2023-08-28 Recalibrate battery level indicator
2024-01-07 Fix drawing of negative temperature zone

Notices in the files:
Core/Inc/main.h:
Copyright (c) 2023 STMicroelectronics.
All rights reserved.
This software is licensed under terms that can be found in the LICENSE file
